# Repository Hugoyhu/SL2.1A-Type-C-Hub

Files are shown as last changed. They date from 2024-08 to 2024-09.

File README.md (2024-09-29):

# SL2.1A Type-C Hub
A simple 4-port USB2 hub based on the SL2.1A design.
This board is designed in KiCAD v7! It is based off an earlier [2021 design](https://github.com/Hugoyhu/Hack-Club-Zephyr-USB-Hub) with USB-A outputs. 

This revises the board to provide USB2 Type-C outputs. By default, the schematic provides circuitry for default USB power (500mA) but resistor values can be changed to provide higher output current if available through external power. 

Schematic Capture
PCB Render
Assembled OSHPark After Dark

These boards have been built and tested.

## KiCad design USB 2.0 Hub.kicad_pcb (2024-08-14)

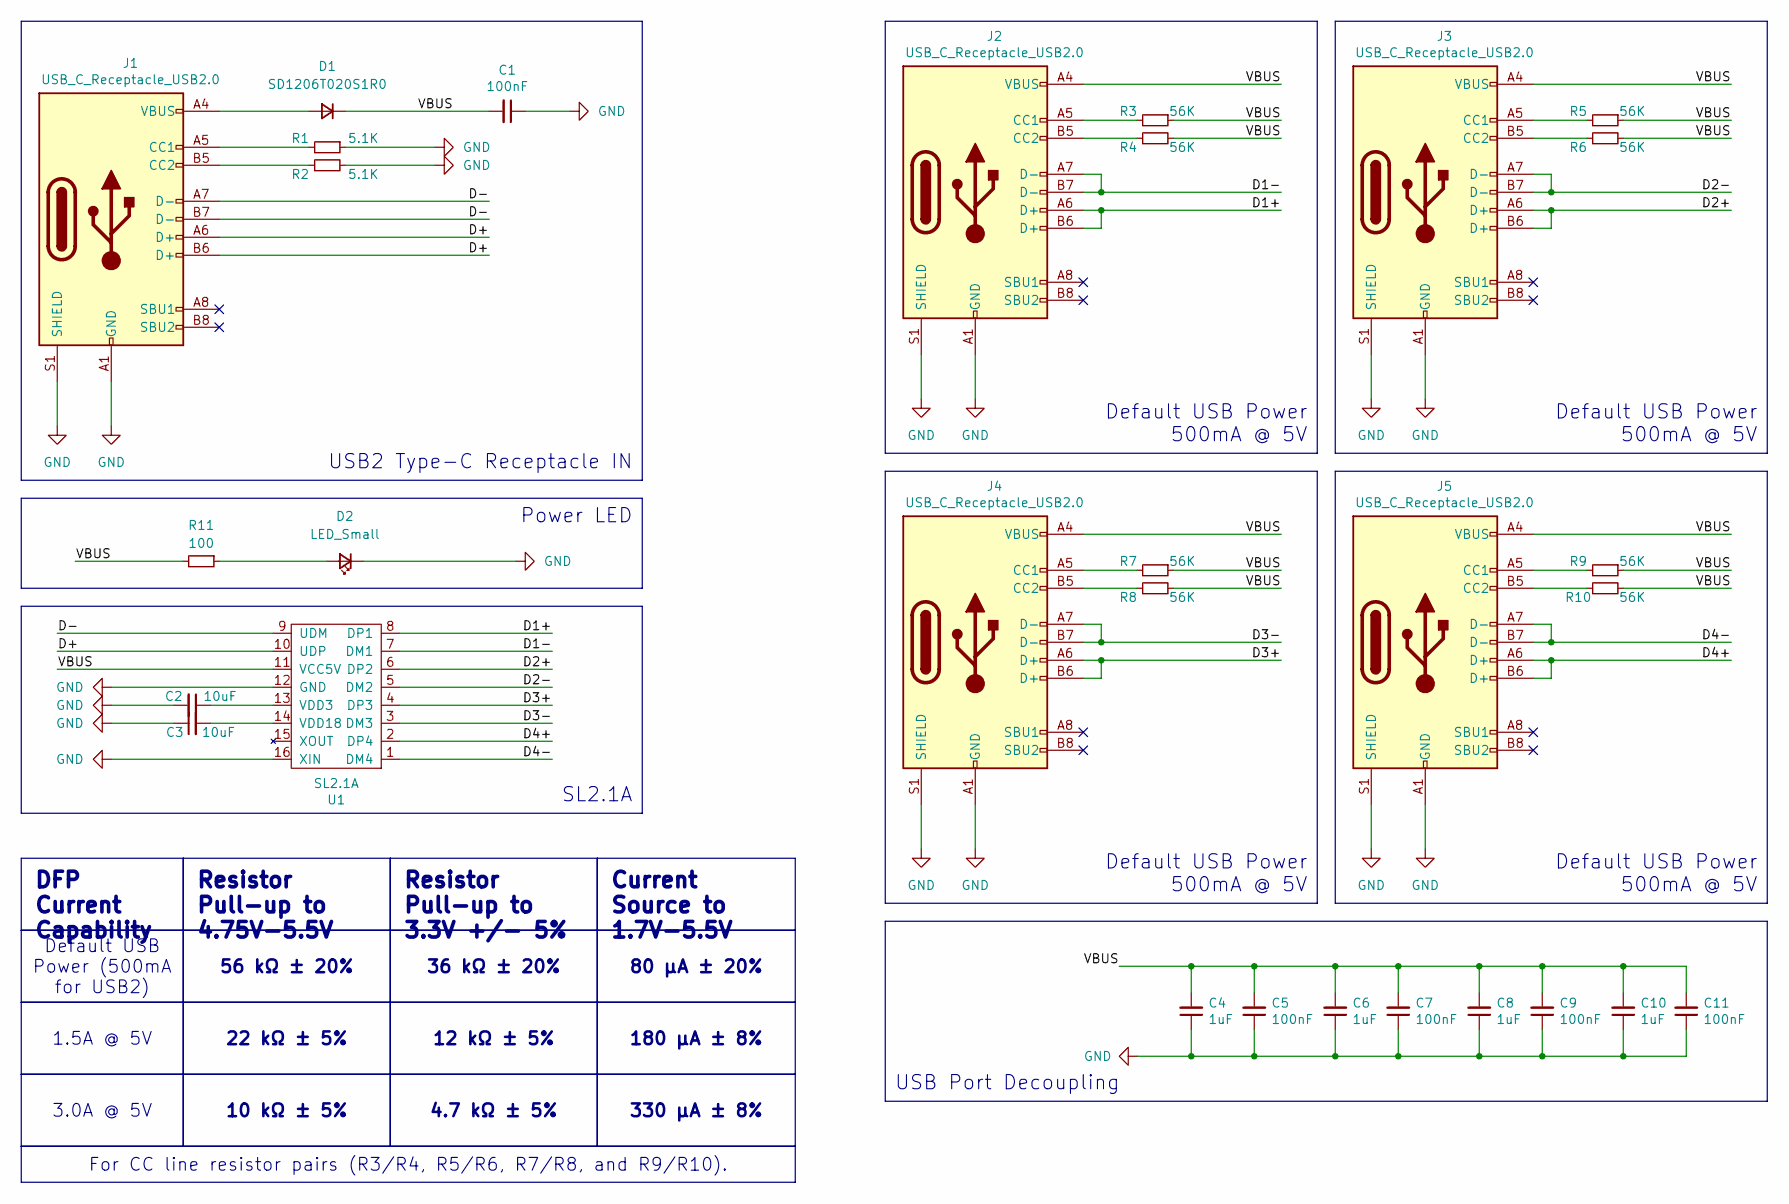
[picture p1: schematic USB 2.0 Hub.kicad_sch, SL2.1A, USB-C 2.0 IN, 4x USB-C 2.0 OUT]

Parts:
C1, C5, C7, C9, C11: 100nF; C_0805_2012Metric_Pad1.18x1.45mm_HandSolder
C2, C3: 10uF; C_0805_2012Metric_Pad1.18x1.45mm_HandSolder
C4, C6, C8, C10: 1uF; C_0805_2012Metric_Pad1.18x1.45mm_HandSolder
D1: SD1206T020S1R0; D_1206_3216Metric_Pad1.42x1.75mm_HandSolder
D2: LED_Small; LED_1206_3216Metric_Pad1.42x1.75mm_HandSolder
J1, J2, J3, J4, J5: USB_C_Receptacle_USB2.0; USB_C_Receptacle_HRO_TYPE-C-31-M-12
R1, R2: 5.1K; R_0805_2012Metric_Pad1.20x1.40mm_HandSolder
R3, R4, R5, R6, R7, R8, R9, R10: 56K; R_0805_2012Metric_Pad1.20x1.40mm_HandSolder
R11: 100; R_0805_2012Metric_Pad1.20x1.40mm_HandSolder
U1: SL2.1A; SOIC-16_4.55x10.3mm_P1.27mm

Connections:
/D1+: J2.A6 (D+), J2.B6 (D+), U1.8 (DP1)
/D1-: J2.A7 (D-), J2.B7 (D-), U1.7 (DM1)
/D2+: J3.A6 (D+), J3.B6 (D+), U1.6 (DP2)
/D2-: J3.A7 (D-), J3.B7 (D-), U1.5 (DM2)
/D3+: J4.A6 (D+), J4.B6 (D+), U1.4 (DP3)
/D3-: J4.A7 (D-), J4.B7 (D-), U1.3 (DM3)
/D4+: J5.A6 (D+), J5.B6 (D+), U1.2 (DP4)
/D4-: J5.A7 (D-), J5.B7 (D-), U1.1 (DM4)
/D+: J1.A6 (D+), J1.B6 (D+), U1.10 (UDP)
/D-: J1.A7 (D-), J1.B7 (D-), U1.9 (UDM)
/VBUS: C1.2, C4.2, C5.2, C6.2, C7.2, C8.2, C9.2, C10.2, C11.2, D1.1 (K), J2.A4 (VBUS), J2.A9 (VBUS), J2.B4 (VBUS), J2.B9 (VBUS), J3.A4 (VBUS), J3.A9 (VBUS), J3.B4 (VBUS), J3.B9 (VBUS), J4.A4 (VBUS), J4.A9 (VBUS), J4.B4 (VBUS), J4.B9 (VBUS), J5.A4 (VBUS), J5.A9 (VBUS), J5.B4 (VBUS), J5.B9 (VBUS), R3.1, R4.2, R5.1, R6.2, R7.1, R8.2, R9.1, R10.2, R11.2, U1.11 (VCC5V)
GND: C1.1, C2.2, C3.1, C4.1, C5.1, C6.1, C7.1, C8.1, C9.1, C10.1, C11.1, D2.1 (K), J1.A1 (GND), J1.A12 (GND), J1.B1 (GND), J1.B12 (GND), J1.S1 (SHIELD), J2.A1 (GND), J2.A12 (GND), J2.B1 (GND), J2.B12 (GND), J2.S1 (SHIELD), J3.A1 (GND), J3.A12 (GND), J3.B1 (GND), J3.B12 (GND), J3.S1 (SHIELD), J4.A1 (GND), J4.A12 (GND), J4.B1 (GND), J4.B12 (GND), J4.S1 (SHIELD), J5.A1 (GND), J5.A12 (GND), J5.B1 (GND), J5.B12 (GND), J5.S1 (SHIELD), R1.1, R2.2, U1.12 (GND), U1.16 (XIN)
unnamed: D1.2 (A), J1.A4 (VBUS), J1.A9 (VBUS), J1.B4 (VBUS), J1.B9 (VBUS)
unnamed: D2.2 (A), R11.1
unnamed: J1.A5 (CC1), R1.2
unnamed: J1.B5 (CC2), R2.1
unnamed: J2.A5 (CC1), R3.2
unnamed: J2.B5 (CC2), R4.1
unnamed: J3.A5 (CC1), R5.2
unnamed: J3.B5 (CC2), R6.1
unnamed: J4.A5 (CC1), R7.2
unnamed: J4.B5 (CC2), R8.1
unnamed: J5.A5 (CC1), R9.2
unnamed: J5.B5 (CC2), R10.1
unnamed: C2.1, U1.13 (VDD3)
unnamed: C3.2, U1.14 (VDD18)

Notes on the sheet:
Resistor Pull-up to 4.75V-5.5V
For CC line resistor pairs (R3/R4, R5/R6, R7/R8, and R9/R10).
22 kΩ ± 5%
12 kΩ ± 5%
330 μA ± 8%
Current Source to 1.7V-5.5V
4.7 kΩ ± 5%
36 kΩ ± 20%
DFP Current Capability
56 kΩ ± 20%
80 μA ± 20%
Resistor Pull-up to 3.3V +/- 5%
180 μA ± 8%
1.5A @ 5V
10 kΩ ± 5%
3.0A @ 5V
Default USB Power (500mA for USB2)
SL2.1A
Default USB Power 500mA @ 5V
USB2 Type-C Receptacle IN
USB Port Decoupling
Power LED

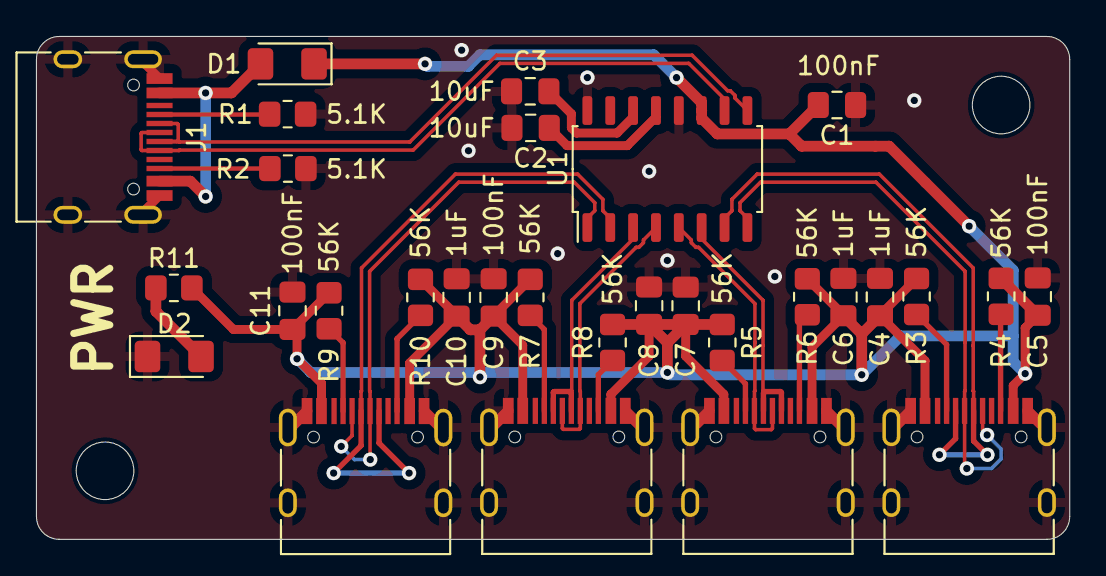
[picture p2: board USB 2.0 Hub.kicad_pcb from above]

Board: 2 copper layers, 57.4 x 27.9 mm, 30 parts (0 on the bottom side), 26 nets.

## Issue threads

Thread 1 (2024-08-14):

DFP Port CC Pulled to Ground

424778940z, 2024-08-14:
DFP CC lines should be pulled high, instead of pull to ground

Hugoyhu, 2024-08-14:
Yes. You are correct. Must have misread something at some point- thank you for pointing this out

Closed 2024-08-14.

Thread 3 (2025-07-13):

[QUESTION] Only two USB

tcastelly, 2025-07-13:
Hello,

Thank you very much for your project.
Is it possible please to tell for using only two USB-C hubs if I need to remove few "decoupling" components (C9/C10 maybe ?).

Thank you very much :)

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

Hugoyhu, 2025-07-14:
Hi Thomas, I believe you would be safe taking off C8-C11. The goal was for 1.1uF on each USB port. That being said, I haven't tested such a setup. If you have space on your board, I'd encourage you to place one or two 1uF capacitors (remove C9, C11) and mark them Do Not Place (DNP), so you have the option of adding additional capacitors if necessary.

tcastelly, 2025-07-16:
Thank you very much @Hugoyhu for your help :)

Closed 2025-07-16.

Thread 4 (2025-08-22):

If using a USB (four-wire) connector instead of USB Type-C, how should the current be controlled without the CC pin?

xzj2004, 2025-08-22:
If using a USB (four-wire) connector instead of USB Type-C, how should the current be controlled without the CC pin?
